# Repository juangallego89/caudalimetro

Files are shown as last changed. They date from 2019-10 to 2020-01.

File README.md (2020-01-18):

# Proyecto IoT para monitorear el consumo de agua en múltiples viviendas

Nombre del proyecto: Diseño e implementación de un sistema IoT para gestionar el consumo de agua en el hogar

Universidad Cooperativa de Colombia 
Facultad de Ingenierías 
Programa de Ingeniería de Sistemas 
Villavicencio, Meta
2020

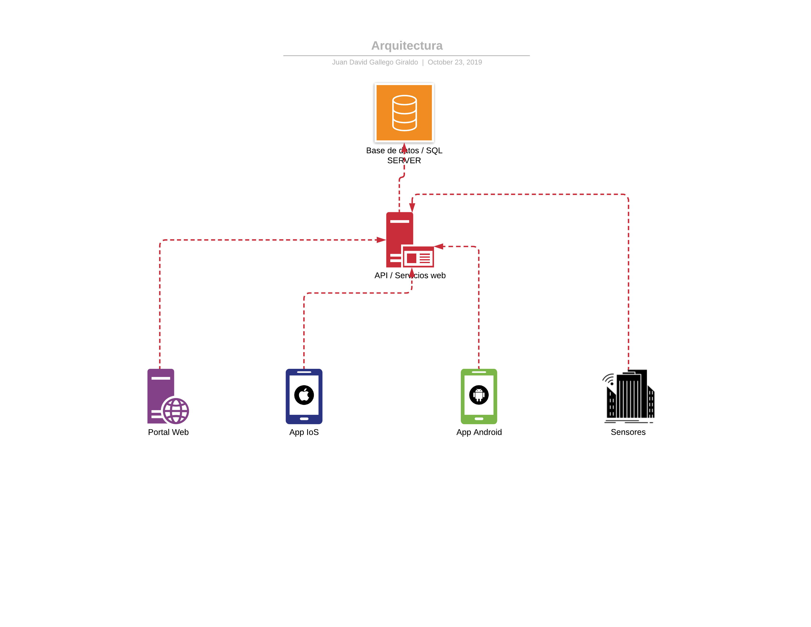
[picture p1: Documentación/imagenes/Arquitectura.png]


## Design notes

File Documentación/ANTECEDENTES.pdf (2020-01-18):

Diseño de un prototipo para la medición del consumo de agua en un grifo de

una unidad habitacional a través de la tecnología ZigBee

Gisell Granados Quitian & Javier Pérez Ombita Junio 2017

Asesor metodológico y técnico

Daniel Bejarano Segura
Lic. Matemáticas y Física

Universidad Cooperativa de Colombia

Facultad de Ingenierías

Programa de Ingeniería de Sistemas

Villavicencio, Meta

Junio, 2017

Contenido

Lista de Figuras

Lista de Tablas

Resumen

Este proyecto de investigación tiene como objetivo de desarrollar un sistema automatizado

que mida y monitoree el consumo de agua, el cual se instala en la tubería que conecta con

diversos grifos de una unidad habitacional, de tal forma que al abrir la llave se sepa con exactitud

el valor de litros de agua que se gastaron en el tiempo de apertura de la llave. El hardware del

prototipo está integrado por un sensor de flujo que mide el gasto en tiempo real y envía los datos

de forma inalámbrica, a través del protocolo de comunicación Zigbee, a una placa de Arduino

mega, esta placa procesa la información y la envía a una base de datos para que el usuario, por

medio de una aplicación móvil, pueda monitorear al consumo. Se usaron varios lenguajes de

programación como JAVA, para el desarrollo de la app y SQL, para el desarrollo de la base de

datos. Se realizó una investigación aplicada con enfoque tecnológico, ya que se transformaron

los conocimientos adquiridos en el desarrollo tecnológico del prototipo. Se pretende automatizar

un proceso que en la actualidad no es posible realizar con facilidad, y es el de monitorear el

consumo del agua por grifo.

Palabras clave: aplicación móvil, consumo de agua, ZigBee.

Abstract

The research project aims to develop an automated system that measures and monitors the

consumption of water, which would be installed in the pipeline that connects with various

faucets within the home, and would measure the exact number of litres of water that were

consumed over a period of time. The prototype hardware would consist of a flow sensor that

measures the real-time water use and sends the data wirelessly through the Zigbee

communication protocol to a Mega Arduino Board. This board processes the information and

sends it to a database. A mobile application can also be used to monitor consumption. Several

programming languages like JAVA were used for the development of the application and SQL

for the development of the database. Applied research is carried out with a technological focus,

since the acquired knowledge in the technological development of the prototype was

transformed. It is intended to automate a process that at present is not possible to perform easily,

and to monitor the consumption of tap water.

Key words: Movil App, water demand, ZigBee.

Introducción

Los cambios climáticos, el consumo inadecuado en los hogares, el aumento y desarrollo de la

población, son algunos de los factores que causan un mayor gasto del agua en la actualidad. Para

el DANE las viviendas tienen una ocupación de entre 4 o menos personas (DANE, 2010, p.2),

las cuales usan el agua ya sea para bañarse, lavarse las manos o cocinar sus alimentos, entre

otros. Ojeda (2009) plantea que el “consumo básico de agua potable en Colombia es de 20

m3/vivienda-mes, equivalente a 133 litros/habitante -día y que este consumo en su mayoría es

30% mayor al estándar” (p.11) es decir que se está consumiendo por hogar más de lo que

corresponde.

En las residencias son usados los contadores o medidores de agua, que son los que se

encargan de registrar el consumo para su posterior cobro, pero en la mayoría de las ocasiones no

registran el total del agua que se consume.

En la actualidad, con el desarrollo y evolución de las tecnologías, se han adoptado mejores

métodos que ayudan a administrar este recurso hídrico que llega a los hogares. Según Bustillos,

Hernández, Silva, Barrón, Chávez, & López (2016), una tecnología actual que ayuda con la

automatización y medición del consumo de agua de las redes domésticas, sin ser creada para

esto, es ZigBee (p. 1), ya que con la integración de otros métodos (sensores, placas electrónicas,

nodos inalámbricos) logra transferir de forma inalámbrica y en tiempo real el consumo de cada

salida de agua, si se requiere.

Con el desarrollo de esta investigación y utilizando tecnologías como ZigBee, Arduino,

sensores entre otras, se pretende ayudar al hombre a obtener la medición exacta del agua que

consume en su hogar y así, contribuir con el ahorro de este líquido vital.

Capítulo 1. Descripción del Proyecto

1.1.Planteamiento del problema

1.1.1. Descripción.

La falta de conciencia en el uso racional y el consumo inadecuado del agua hacen evidente la

necesidad de medir el gasto en tiempo real del consumo que se hace en una unidad habitacional.

Actualmente, para medir el consumo son utilizados los medidores de agua, contadores o

hidrómetros, los cuales permiten contabilizar la cantidad de agua que pasa a través de ellos.

Según Ojeda (2009), “el mal uso que se le da al agua en los hogares es que el 52% del agua

suministrada no se contabiliza, el 48% del agua suministrada se factura y el 28% del valor del

agua suministrada se recauda” (p.11), es decir que, en muchas ocasiones estos medidores de agua

no registran la totalidad del líquido que entra a una vivienda y esto conlleva a tener un deficiente

control del uso.

Cada vez que una persona quiere saber el consumo de agua en tiempo real de una vivienda

debe ir hasta el contador y observar el registro que este está indicando, de otra forma, se deben

esperar los reportes que llegan a los hogares de manera mensual, y para esto, esperar a que un

funcionario de la empresa del acueducto realice la lectura del contador.

El problema es mayor cuando se desea conocer permanentemente el consumo de cada grifo;

al tener un único contador esto resulta imposible porque este capta al mismo tiempo el consumo

de los grifos que estén en uso, ya sea uno o más.

Pasa de igual forma si la persona quiere saber el valor de su consumo general o por grifo,

como no tiene acceso en tiempo real a los datos que registra el contador, debe esperar a que

llegue su factura, teniendo en cuanta que va a ser general y no por grifo.

Estas problemáticas se podrían solucionar si se creara un dispositivo tecnológico que ayude a

monitorear el consumo de cada salida de agua o grifo y así se tendría registro en tiempo real del

consumo, además de calcular el valor del gasto parcial y total que se genera en una unidad

habitacional.

1.1.2. Formulación del Problema.

La presente investigación consiste en el diseño de un prototipo, apoyados en la tecnología

Zigbee, que facilite el monitoreo en tiempo real de un punto de consumo de agua; para lo

anterior, se puede formular la siguiente pregunta de investigación:

¿Es posible monitorear en tiempo real el consumo de agua en un grifo de una unidad

habitacional?

1.2.Objetivos

1.2.1. Objetivo general.

Desarrollar un prototipo que ayude a la medición y monitoreo del consumo de agua en un

grifo de una unidad habitacional.

1.2.2. Objetivos específicos.
- Construir un prototipo para la medición del consumo de agua de un grifo de una unidad

habitacional.

- Desarrollar una base de datos para almacenar la información del consumo de agua que

genera el grifo.

- Implementar la tecnología Zigbee como medio de transmisión inalámbrico de los datos

del prototipo a la base de datos.

- Desarrollar una aplicación móvil que monitoree el consumo de agua en un grifo de una

unidad habitacional.

1.3.Justificación

Este proyecto de investigación pretende contribuir al uso eficiente y consciente del agua,

creando un prototipo que monitoree el consumo en tiempo real. Lo anterior se da ya que se

encontró que el actual sistema para medir el consumo no registra exactamente el gasto del fluido

que ingresa a las tuberías, además de que no muestra en tiempo real el gasto que se hace por

salida de agua o grifo de una unidad habitacional.

El proyecto tiene el objetivo diseñar un prototipo que ayude al registro y control del agua, ya

que en la actualidad se está viendo que no se le da un buen y adecuado uso en las viviendas por

parte de las personas que las habitan.

El prototipo posibilita el monitoreo en tiempo real del gasto del agua por cada salida que

exista en la unidad habitacional, registrándolo en una aplicación móvil (APP) para que el usuario

sepa sobre su consumo y así mismo si está accediéndolo tome consistencia y realice control del

consumo.

Se emplea la tecnología Zigbee ya que es el protocolo que más se adapta a la investigación,

permitiendo la comunicación inalámbrica entre los diferentes nodos del prototipo y la transmisión de información a la base de datos, además los módulos que se utilizan consumen

energía solo cuando se están usando, de manera contraria están en un estado de poco consumo.

El proyecto se desarrollará en la modalidad de grado de auxiliar de investigación, del proyecto

“Diseño e implementación de un sistema de monitoreo y concientización del consumo de agua

en grifo comercial utilizado en unidades habitacionales basado en el protocolo de internet de las

cosas”, liderado por el Magister en educación Daniel Bejarano y el Magister en seguridad

informática Carlos Ignacio Torres, de la facultad de ingenierías de la Universidad Cooperativa

de Colombia, sede Villavicencio, dentro de la línea de investigación de desarrollo de software.

El área de aplicación se consideró porque teniendo una unidad habitacional un contador no es

posible monitorear en tiempo real el consumo de cada grifo, esto se mejorará con desarrollos

tecnológicos que ayuden a la administración del líquido en los hogares.

1.4.Marco Referencial

Para desarrollar el prototipo es importante tener claro los conceptos teóricos que soportan

la investigación.

1.4.1. Marco Teórico.

1.4.1.1.Zigbee.

ZigBee es un protocolo de comunicación inalámbrico que se basa en el estándar IEEE

802.15.4 de las redes inalámbricas WPAN (Acevedo & Turriago, 2013, p.1).

Esta tecnología es impulsada por ZigBee Alliance y permite interconectar más de 2 nodos

logrando transferencia de datos. Maneja velocidades de transmisión entre 20 y 250 Kbps,

funcionando en la banda sin licencia de 2,4 GHz Osorio, (Garzón & Giraldo, 2008, p.3), para enlaces con alcance de 40 m en interiores (edificio de oficinas, domicilios) y 120 m en exteriores

(con línea de vista).

Este protocolo es utilizado actualmente para desarrollos en domótica, gracias a su poco

consumo de energía, la topología de red en malla y su fácil integración con elementos

electrónicos; su aplicación facilita procesos de monitoreo, control de iluminación, calefacción,

riego.

Esta tecnología soporta tres tipos de topología:

- Estrella: presenta larga vida útil como consecuencia del bajo consumo que requiere.
- Malla: en la cual existen múltiples rutas para alcanzar un destino, obteniéndose alta

confiabilidad.

- Racimo de Árbol: es una topología del tipo Malla-Estrella que encierra los beneficios

de ambas.

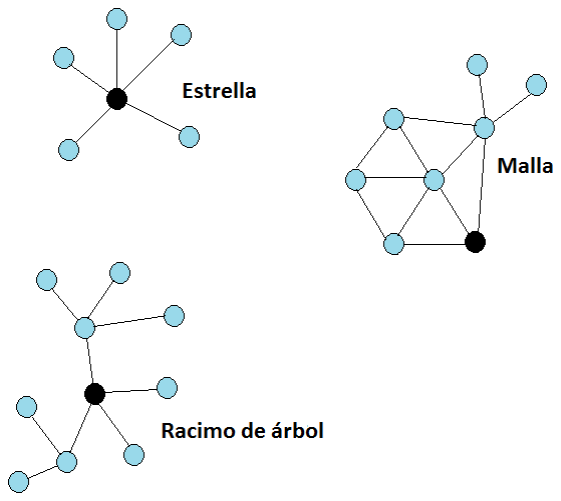
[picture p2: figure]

Figura 1. Topologías. Fuente: Elaboración propia.

1.4.1.2.Módulo XBee.

Los módulos XBee son fabricados por DIGI y están basados en el protocolo de ZigBee, estos

chips son capaces de comunicarse de forma inalámbrica con otros. Según Algarín (2012) “se

puede constituir una red de datos confiable, con alta inmunidad al ruido, facilitando la

comunicación entre los componentes del sistema y asegurando el correcto transporte de la

información desde y hacia las unidades remotas” (p.3).

1.4.1.3.Medidores de flujo de agua domiciliaria.

Cuando se habla de medidores de flujo de agua o caudal, se hace referencia a un instrumento

ubicado en la tubería, que es capaz de contabilizar la cantidad (en volúmenes) de agua que pasa

por ella; según Ordoñez (2007) “los medidores que existen en el mercado miden flujos desde

mililitros por segundo (ml/s) para experimentos precisos de laboratorio, hasta miles de metros

cúbicos por segundo (m³
/s) para sistemas de irrigación de agua o agua municipal” (p.4).

A continuación, se observan los tipos de medidores que existen:

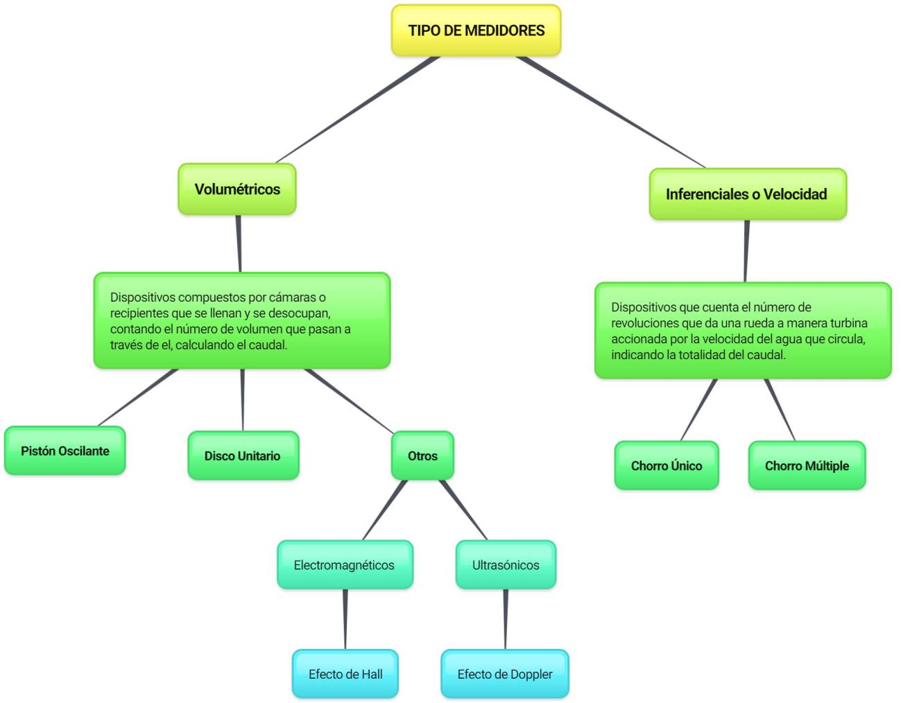
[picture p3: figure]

Figura 2. Tipos de medidores de caudal. Fuente: Elaboración propia.

1.4.1.4.Arduino.

En la página web de Arduino se encuentra que, Arduino es una plataforma electrónica de

código abierto basado en hardware y software, fácil de programar y de usar. Las placas de

Arduino son capaces de leer señales de sensores y convertirlas en salidas (la activación de un

motor, encender un LED, publicar algo en línea). Para ello utiliza el lenguaje de programación de

Arduino, y el software de Arduino (IDE), basadas en el procesamiento.

Este microcontrolador se utiliza en miles de proyectos de diferentes áreas por su característica

de código abierto y su compatibilidad con un sin número de sensores, dispositivos de

comunicación, leds, servo motor, entre otros.

1.4.1.5.Base de datos.

“Una base de datos es un conjunto de elementos de datos interrelacionados, administrados

como unidad” (Oppel, 2010, p. 16). Las bases de datos han ido avanzando al mismo tiempo que

las tecnologías, los registros muestran que fueron las cintas magnéticas las primeras bases de

datos utilizadas, en las cuales se almacenaba la información y solo podía ser leída de forma

secuencial y ordenada.

Existen herramientas que facilitan el uso, la actualización y la consulta de una base de datos,

estas herramientas son los Sistemas Gestores de Bases de Datos (SGBD), que cumplen las

funciones de:

- Permitir a los usuarios almacenar, acceder, actualizar datos.
- Permitir el acceso a los datos por varios usuarios al mismo tiempo, es decir la

concurrencia.

- Salvaguardar la información que exista en la base de datos, de manera que no se

pierda.

- Asegurar la información, de modo que solo los usuarios que tengan permiso de

acceder a la base de datos puedan ver la información.

Algunos SGBD más utilizados son: Oracle, MySQL, PostgreSQL, Microsoft SQL Server.

1.4.1.6.Aplicaciones móviles.

La palabra aplicaciones viene del inglés “apps” que se deriva de “application” y que en

español traduce “aplicación”. Se conoce como aplicación móvil al software que se instala en un

dispositivo móvil con el fin de ampliar sus funcionalidades, para que el usuario realice diferentes

tareas (Arroyo 2011, p. 36)

Según Aguado& Martínez (2013), “el entorno actual de los contenidos y aplicaciones móviles

no es consecuencia directa del desarrollo lineal y planificado de un modelo inicial, si no que ha

surgido como resultado de la evolución vivida el negocio de las telecomunicaciones y su

confluencia con otros mercados” (p. 14).

Es probable que ya existan aplicaciones para todo: jugar, estudiar, enviar mensajes, escuchar

música, ver películas, publicar información, controlar aparatos, navegar por internet etc., pero

cada día surgen necesidades en la sociedad que deben ser solucionadas de distintas maneras y

con nuevas aplicaciones.

Se pueden desarrollar aplicaciones en diferentes lenguajes de programación como Java, C#,

Visual Basic, Objective-C, Swift, entre otros, teniendo en cuenta el sistema operativo para el cual

se diseñe la aplicación.

Entre los sistemas operativos más utilizados por dispositivos móviles están:

Android.

Es un sistema operativo multidispositivo, inicialmente diseñado para teléfonos móviles. En la

actualidad se puede encontrar en ordenadores, tabletas, GPS, televisores, etc. Este sistema

operativo permite programar aplicaciones empleando Java (Robledo& Fernández 2011, p.12).

Fue desarrollado por la compañía Android Inc, que en el año 2005 fue comprada por Google.

Actualmente Android es ejecutado como sistema operativo en múltiples teléfonos de mascas como: Samsung, LG, Lenovo, Motorola, Sony, Wuawei, entre otros, siendo el sistema operativo

que en la actualidad tiene mayor presencia en los móviles.

IOS.

Nace a mediados de año 2007, llamándose IPhone OS. Es desarrollado originalmente para el

IPhone, pero más tarde fue introducido a el IPod Touch y el IPad, desde si primera versión

incorpora aplicaciones como Mail, Fotos, Calculadora, entre otras. Utiliza como lenguaje de

programación para crear sus aplicaciones Objective-C y Swift.

BlackBerry OS.

Es desarrollado por RIM, este sistema operativo es propietario de BlackBerry. La versión del

sistema operativo tiene un Kernel que se basa en Java, además, es un sistema operativo

multitarea, pues permite ejecutar más de una aplicación al tiempo. Sus aplicaciones móviles son

desarrolladas en Java, en diferentes entornos de desarrollo.

Windows Phone.

Este sistema operativo fue lanzado en el año 2010. Entre las novedades se encuentra la

denominada interfaz de usuario “Metro” basada en la utilización de mosaicos dinámicos que

muestran información útil al usuario. Actualmente corre en teléfonos de Microsoft, la linea de

teléfonos que le compro a Nokia en el año 2013 y se utilizan como lenguajes de programación

C# y Visual Basic.

1.5.Metodología

Para esta investigación se han aplicado dos metodologías, las cuales son la metodología de

investigación y la metodología de ingeniería

1.5.1. Metodología de Investigación.

La presente investigación es de tipo aplicada con enfoque tecnológico, ya que se pretende

transformar el conocimiento adquirido en el desarrollo tecnológico de un prototipo que va a

satisfacer una necesidad social previamente identificada.

El método tecnológico cuenta con las siguientes fases (Ortiz 2005, p.43).

- Selección del problema
- Desarrollo de hipótesis
- Prueba de hipótesis
- Comprobación de resultados
- Comunicación
1.5.2. Metodología Ingenieril.

Se hizo un análisis de las diferentes metodologías de desarrollo que existen y se concluyó que

la mejor opción a aplicar es la metodología de prototipos, porque se acopla a las necesidades del

proyecto permitiendo escuchar los requerirnos iniciales del tutor para hacer un primer modelo

funcional, con el cual se podrá interactuar y si es el caso hacer cambio en las siguientes

iteraciones.

Esta metodología reduce el riesgo de construir un producto que no satisfaga las necesidades

del tutor.

Para ejecutar esta metodología se tienen en cuenta sus etapas que son las siguientes

(Pressman, 2005, p. 39).

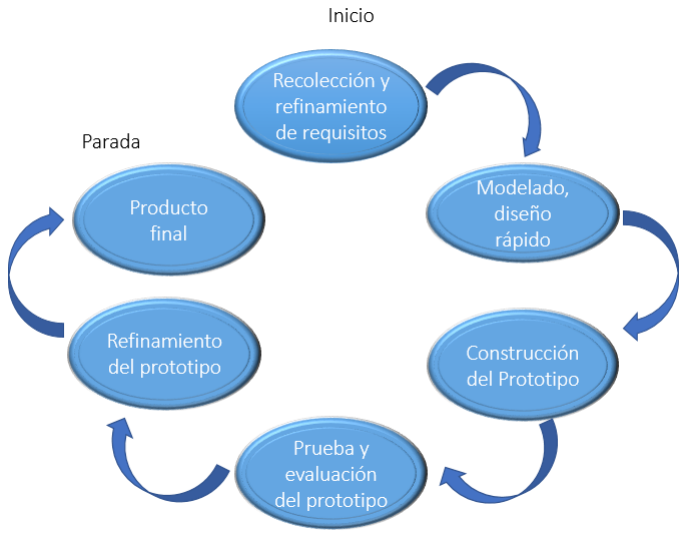
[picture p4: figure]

Figura 3. Fases de la metodología prototipos. Fuente: Elaboración propia.

Capítulo 2. Descripción De Las Actividades Realizadas

Con el desarrollo de la investigación se realizaron diferentes actividades para poder construir

el prototipo funcional, de igual manera se establecieron reuniones entre los tutores y los

auxiliares de investigación y para tener claros los objetivos finales del proyecto.

Se estableció un cronograma (ver figura 4) para facilitar el desarrollo de las actividades y

tener clara la fecha de inicio y fin de cada actividad que comprende el proyecto.

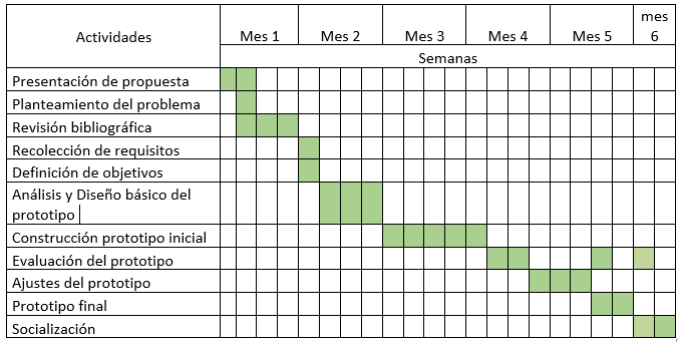
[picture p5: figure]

Figura 4. Cronograma de actividades. Fuente: Elaboración propia.

2.1.Presentación De La Propuesta Y Planteamiento Del Problema

Se presentó el proyecto de investigación “Diseño e implementación de un sistema de

monitoreo y concientización del consumo de agua en grifo comercial utilizado en unidades

habitacionales basado en el protocolo de internet de las cosas” por parte del Magister en

educación Daniel Bejarano, quien es el investigador principal y el Magister en seguridad informática Carlos Torres a dos de los estudiantes del programa de Ingeniería de Sistemas, los

cuales tomarían el papel de auxiliares de investigación.

De igual manera, se planteó la problemática a solucionar y se trazaron unos objetivos a

cumplir.

2.2.Revisión Bibliográfica

Después de tener claro la problemática a solucionar, se realiza una investigación documental

en diferentes fuentes de información como bases de datos, bibliotecas, bibliotecas virtuales, en

las cuales se logra recopilar diferentes trabajos, libros, tesis, revistas, artículos con información

sobre tecnologías inalámbricas, consumo de agua, aplicaciones móviles, bases de datos,

metodologías; información que es de vital importancia para adquirir nuevo conocimiento.

Se diseñan algunas fichas bibliográficas (ver los anexos), en las cuales se destaca la

información más relevante e importante para aplicar en el desarrollo del proyecto.

2.3.Recolección De Requisitos

Se establecieron con los tutores del proyecto los requerimientos, los cuales estuvieron sujetos

a actualizaciones durante la fase de evaluación del prototipo. A continuación, se mencionan los

requerimientos tanto funcionales como no funcionales del proyecto.

2.3.1. Requerimientos no Funcionales.

Tabla 1. Requerimientos no funcionales.

ID | Nombre | Descripción
R-01 | Usabilidad | El prototipo debe ser fácil de usar por el usuario

R-02 | Disponibilidad | El prototipo debe ser funcional para que el usuario lo utilice cada vez que lo requiera
R-03 | Aplicación móvil para Android | La aplicación será compatible con los teléfonos que tengan como sistemas operativo Android
R-04 | Interfaz amigable | La interfaz de la aplicación debe poder utilizarse por el usuario de forma fácil y sencilla.

Fuente: Elaboración propia.

2.3.2. Requerimientos Funcionales de la APP.

Tabla 2. Requerimientos funcionales.

ID | Nombre | Descripción
R-01 | Visualizar consumo | El sistema proporciona la información al usuario del consumo de agua
R-02 | Visualizar costo de consumo | El sistema proporciona la información al usuario del costo en pesos del consumo de agua
R-03 | Actualizar | Se actualizan los datos de consumo y costo de consumo de agua.

Fuente: Elaboración propia.

2.4.Definición de Objetivos

De acuerdo con las necesidades y requerimos que se establecieron, surgieron los objetivos que

como auxiliares de la investigación se debieron cumplir. Estos objetivos, el general y los

específicos, se pueden observar en el primer capítulo del documento.

2.5.Análisis Y Diseño Básico Del Prototipo

Gracias a los requerimientos funcionales recopilados, se diseña el diagrama de casos de uso

como base para empezar la construcción del prototipo.

2.5.1. Casos de uso para la APP.

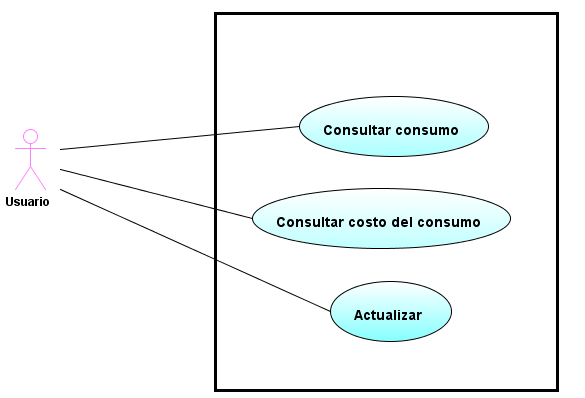
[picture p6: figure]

Figura 5. Casos de uso. Fuente: Elaboración propia.

2.6.Construcción del Prototipo

La construcción del prototipo se divido en 4 fases por ser un proyecto que integra diferentes

componentes electrónicos y tecnológicos.

Tabla 3. Componentes electrónicos utilizados para la construcción del prototipo.

Concepto | Descripción | Cant.
Módulo XBee | Módulo de comunicación por radio | 2
Arduino Mega | Tarjeta de desarrollo basada en un microcontrolador | 2

G1/2 Sensor de flujo de agua | Sensor de flujo de agua | 1
Unidad XBee Explorer USB | Tarjeta para programar los módulos XBee | 1
Unidad regulada para módulos XBee | Tarjeta reguladora de voltaje. | 2
Base SMD de 10 pines y 2mm para XBee | Base SMD de 10 pines y 2mm para XBee | 4
Header hembra para Arduino | Conector header hembra de 6 pines para Arduino. | 2
Conector header macho | Conector header macho de 40 pines, en una línea. | 1

Fuente: Elaboración propia.

Tabla 4. Componentes tecnológicos utilizados para la construcción del prototipo.

Concepto | Descripción
XCTU | Aplicación para configurar, inicializar, actualizar firmware y testear los módulos XBee.
MySQL | SGBD utilizado para almacenar la información que genera el sensor de caudal.
XAMMP | Programa que permite la gestión de bases de datos MySQL y servidor web Apache.
JSON | (JavaScript Object Notation - Notación de Objetos de JavaScript) es un formato ligero de intercambio de datos.
PHP | Lenguaje de código libre.
Android Studio | IDE para desarrollar la aplicación móvil.

Fuente: Elaboración propia.

2.6.1. Construcción Simulación Del Grifo.

Para fabricar una simulación de un grifo se utilizaron los siguientes materiales:

- 01 botellón de agua con capacidad de 20 litros.
- Silicona trasparente.
- 1 llave de grifo PVC.
- Pegante para PVC.
- 30 cm de tubo PVC de (1/2) pulgada.
- 01 reducción de 1(1/4) a (1/2) pulgadas.
- 01 codo PVC de (1/2) pulgada.
- 02 adaptadores hebra PVC de (1/2) pulgada.
- 01 base metálica ornamentada para sostener el botellón.

Una vez ensamblados estos elementos, se obtuvo un grifo con la suficiente capacidad de agua

para realizar las respectivas pruebas del prototipo.

Se instaló el sensor de caudal antes de la salida final de agua como lo muestra la figura 5, para

calcular en este punto el volumen de líquido que saldrá.

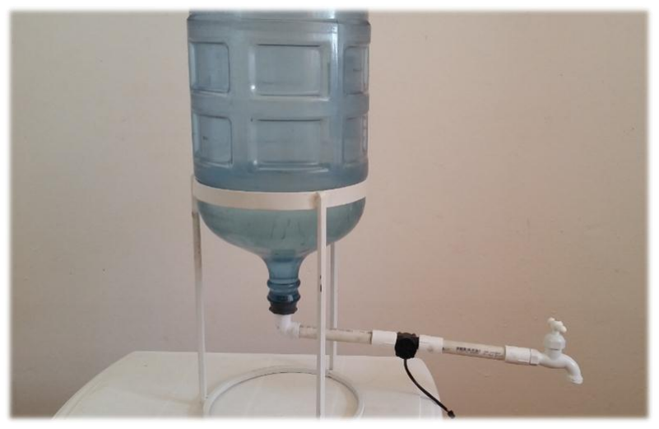
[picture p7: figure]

Figura 6. Foto de la simulación del grifo. Fuente: Elaboración propia.

2.6.2. Construcción De Base De Datos.

El prototipo requiere del desarrollo de una base de datos para almacenar la información del

consumo de agua, información que emite el sensor de caudal que se instaló en la tubería que

lleva al grifo. La base de datos se desarrolló en el sistema de gestión de base de datos o SGBD

MySQL y se diseñó un modelo entidad relación pensado en la implementación de un sistema

completo que cuente con varios nodos terminales que envían información a uno central, pero que

permita por el momento realizar pruebas con un solo nodo

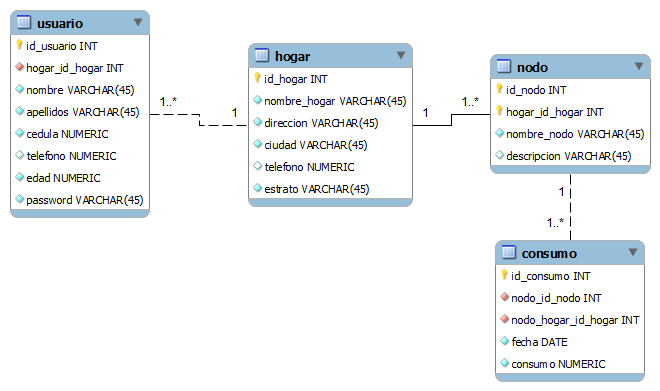
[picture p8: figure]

Figura 7. Modelo entidad relación (MER) del prototipo. Fuente: Elaboración propia.

El eje central de la base de datos es el hogar (ver Figura 7.) en el cual se instalará el sistema.

Esta unidad habitacional tendrá unos usuarios que tendrán acceso a la información que vayan

capturando los diferentes nodos.

2.6.3. Construcción De Nodos.

Como medio de transmisión de datos se utilizaron 02 módulos Xbee SC2. Uno es el nodo

emisor, el cual se encargará de enviar las pulsaciones emitidas por el sensor de caudal que está

en la tubería, cada vez que salga agua por el grifo.

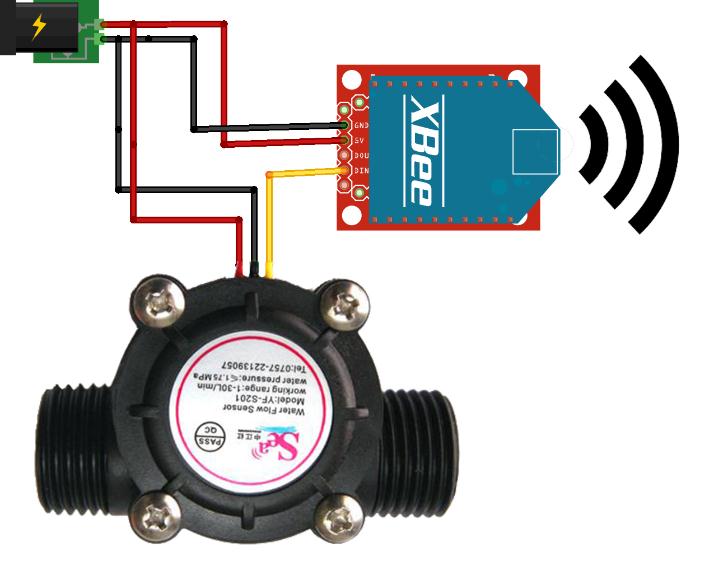
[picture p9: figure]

Figura 8. Conexión del sensor con el módulo XBee emisor. Fuente: Elaboración propia.

El segundo nodo recibirá la información transmitida y la enviará al pin 2 de la placa Arduino

que se encargará de procesar la información.

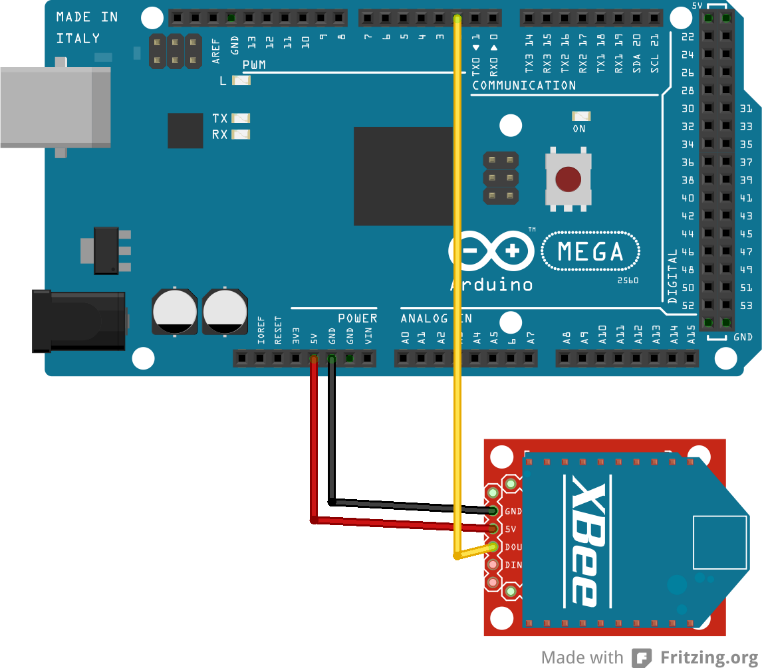
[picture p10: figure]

Figura 9. Conexión de la placa Arduino con el módulo receptor XBee. Fuente: Elaboración propia.

Las placas de Arduino, en este caso la versión Mega 2560, cuentan con pines para diferentes

propósitos como entradas o salidas digitales, análogas, PWM, entre otros. Pero específicamente

los pines 2 y 3 están programados para realizar conteos de pulsaciones digitales, con el fin de

hallar su frecuencia mediante la función attachInterrupt(). Obteniendo la frecuencia, se logra

hacer una conversión a caudal (Q), por medio de la utilización de una constante de conversión

(K) que es suministrada por el fabricante de sensor de caudal.

### f(Hz) = K ∗ Q(l min) → Q (l⁄min) =

### f(Hz)

K

⁄

Figura 10. Fórmula para determinar la frecuencia. Fuente: Elaboración propia.

Para el sensor de caudal YF-S201 de 1⁄2 ", la constante de conversión es K=7,5.

El promedio de salida de agua por el grifo se calculó en 1.75 litros. Sin embargo, el promedio

que arrojaba el sensor era de 1.42 litros. Por este motivo se tuvo que ajustar la constante K, con

ayuda de la formula ya expuesta.

Q (l⁄min) =

f(Hz)
K

1,75 (l⁄min) =

10,5(Hz)
K

K = 6

Figura 11. Constante de conversión K. Fuente: Elaboración propia

De esta manera se comprobó que cada sensor necesita de una calibración, para lograr una

medición más exacta.

Las mediciones se envían a la base de datos mediante un web service programado en PHP,

teniendo en cuenta que para la base de datos se utilizó MySQL.

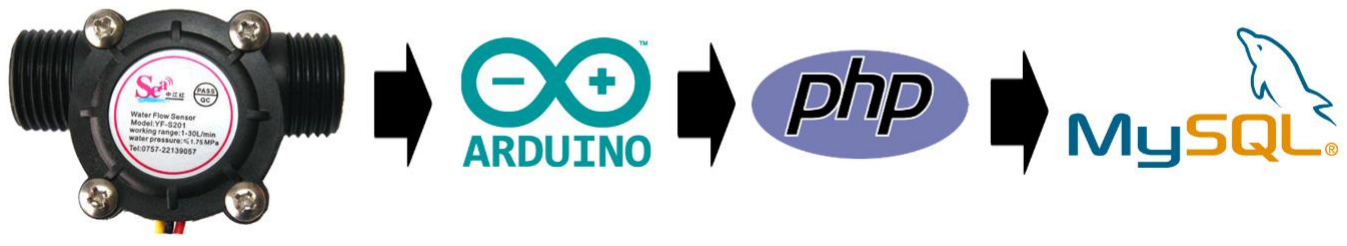
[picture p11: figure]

Figura 12. Herramientas utilizadas para almacenar los datos de consumo. Fuente: Elaboración propia.

2.6.4. Construcción Aplicación Móvil.

Teniendo en cuenta que para realizar las pruebas al prototipo se utilizará un servidor local, se

utilizó el IDE Android Studio para desarrollar la aplicación móvil, ya que este entorno facilita la

organización de los proyectos, separando la parte lógica de las vistas y sus recursos. Además,

permite el uso de bases de datos en MySQL mediante la utilización de web services y la

interacción con JSON (JavaScript Object Notation) para transmitir información desde PHP a la

aplicación.

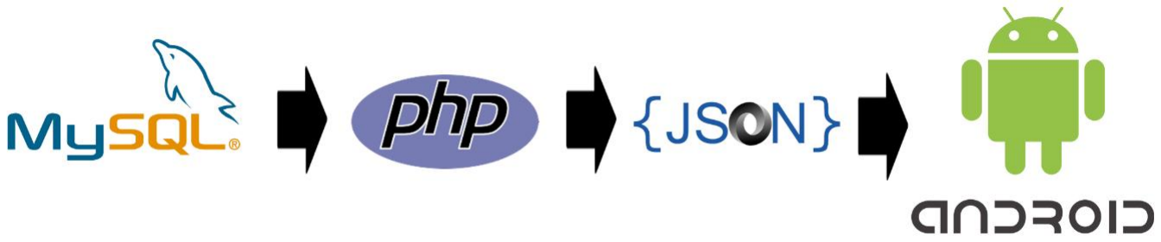
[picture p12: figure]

Figura 13. Herramientas utilizadas para visualizar los datos del consumo. Fuente: Elaboración propia.

La interfaz de la aplicación nos ofrece dos campos tipo TextView en los cuales se refleja la

suma total del consumo de agua hasta la fecha, en metros cúbicos y el valor de este consumo en

pesos colombianos, en base a la tarifa actual que ofrece la empresa de acueducto y alcantarillado

en la ciudad de Villavicencio. Finalmente, la aplicación cuenta con un botón que actualiza la

información de la base de datos, si se han realizado nuevos registros por parte del sensor de

caudal.

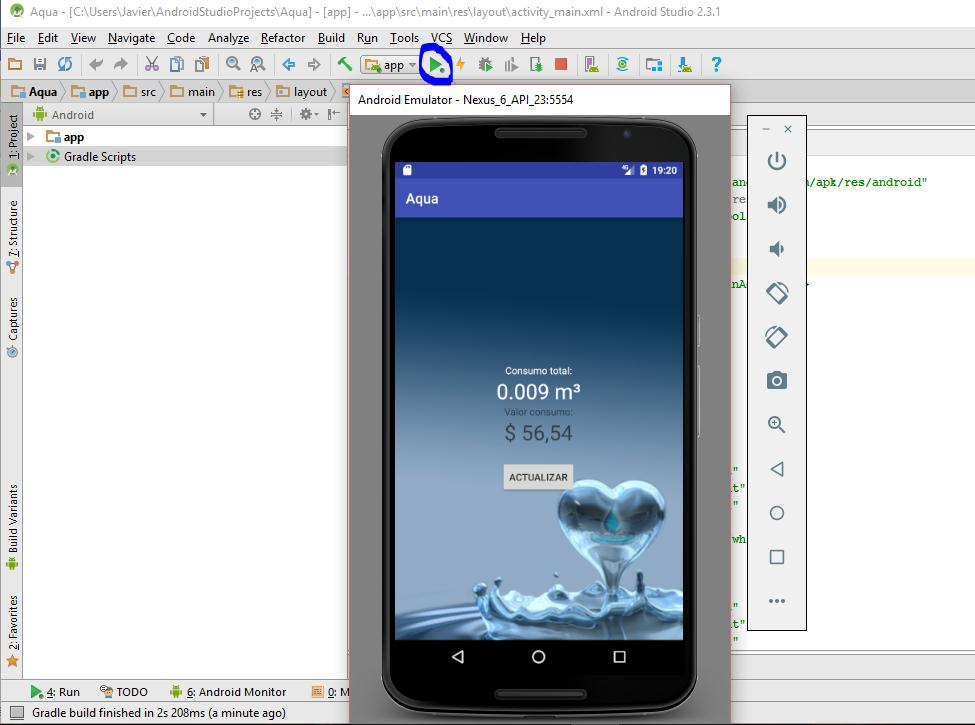
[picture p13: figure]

Figura 14. Visualización de la aplicación móvil. Fuente: Elaboración propia.

2.7.Evaluación Del Prototipo

Para evaluar el prototipo se tuvieron en cuenta criterios como la funcionalidad, la facilidad de

uso, la compatibilidad, la estabilidad, la interoperabilidad, la actualización y el costo final y

futuro del prototipo. Además de esto, se tuvo en cuenta por parte de los tutores que se cumpliera

los objetivos trazado. En los nexos se pueden observar la evaluación que se realizó .

### 2.8. Ajuste del Prototipo

Durante la construcción de prototipo en la fase de la construcción de los nodos se hizo un

análisis para hallar la constante K, ya que para el sensor de caudal YF-S201 de 1⁄2 ", la constante

de conversión es K=7.5 según su fabricante. Al hacer las pruebas se observó que el promedio de

salida de agua que arrojaba el sensor era de 1.42 litros, este valor no coincidía con el promedio

que se había calculado el cual era de 1.75 litros. Por este motivo se tuvo que ajustar la constante

K de la siguiente forma:

Q (l⁄min) =

f(Hz)
K

1,75 (l⁄min) =

10,5(Hz)
K

K = 6

Figura 15. Constante de conversión K. Fuente: Elaboración propia

De esta manera se comprobó que cada sensor necesita de una calibración, para lograr una

medición más exacta.

### 2.9. Prototipo Final

2.9.1. Descripción del Prototipo.

Gracias a la integración de diferentes componentes electrónicos y tecnológicos se logra

diseñar y construir un prototipo completamente funcional, el cual mide en tiempo real el

consumo de agua de un grifo y calcula el valor de este consumo.

Este prototipo pretende comprobar la posibilidad de medición de agua en un grifo de una

unidad habitacional, mediante la utilización del protocolo de transmisión de datos Zigbee.

Para dicho propósito se usará una simulación de un grifo de agua, que realizará las

mediciones del flujo de líquido mediante la utilización de un sensor de caudal de efecto Hall.

Esta información se almacenará en una base de datos, para poder verificarla mediante una

aplicación móvil, desarrollada en el sistema operativo Android.

El prototipo completo permitirá realizar las siguientes acciones:

1) Efectuar las mediciones de flujo de agua en la simulación de un grifo.
2) Enviar la información a un nodo central, para procesarla y almacenar en una base de

datos los resultados.

3) Acceder a la información de la base de datos mediante una aplicación móvil.
4) Brindar la opción de actualizar la información reflejada en la aplicación móvil, si se

realizan nuevas mediciones.

2.9.2. Componentes.

El prototipo final se compone de una simulación de un grifo de agua (ver Figura 16), en el que

se encuentra instalado un sensor de caudal, el cual se encarga de determinar cuándo está

circulando el agua por la tubería.

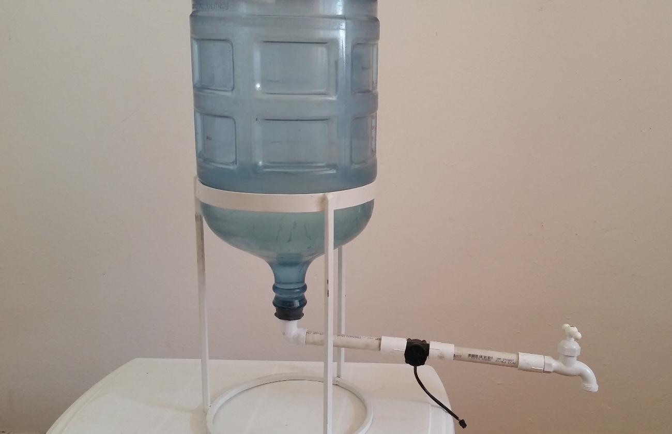
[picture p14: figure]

Figura 16. Simulación del grifo de agua con el sensor. Fuente: Elaboración propia.

Existe un nodo terminal que está compuesto por un módulo XBee, el cual está conectado con

el sensor de caudal para transmitir la información (pulsaciones) que arroja el sensor cada vez que

se abre el grifo y pasa el agua.

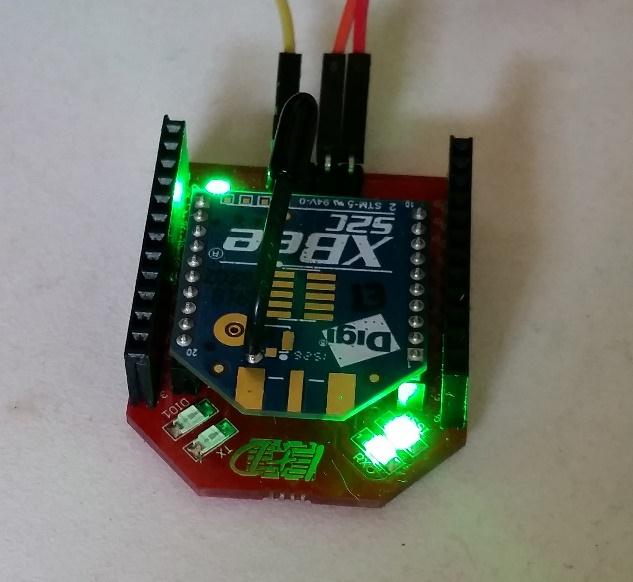
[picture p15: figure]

Figura 17. Nodo Terminal. Fuente: Elaboración propia.

De igual forma existe un nodo coordinador (ver Figura 18) que se encarga de recibir la

información que es emitida por el nodo terminal. Este nodo está compuesto por una placa

Arduino y un módulo XBee.

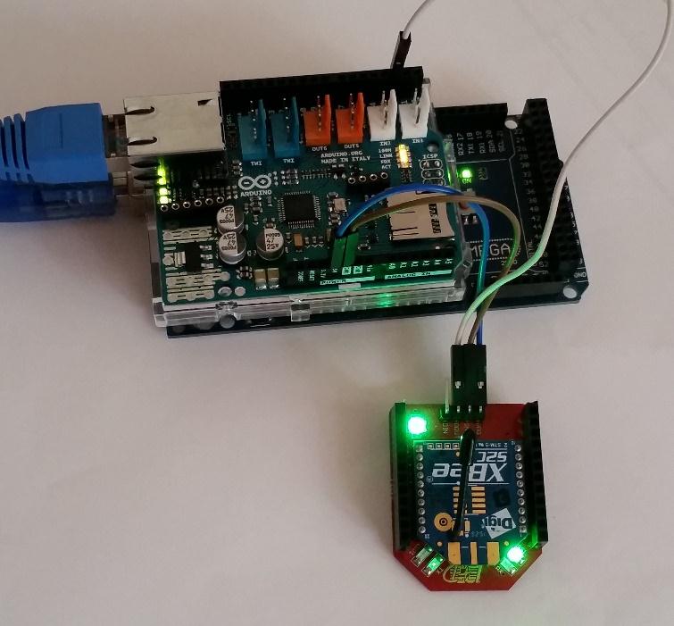
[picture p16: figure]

Figura 18. Nodo coordinador. Fuente: Elaboración propia.

Luego de que la información llega al nodo coordinador, es enviada a la base de datos, para ser

almacenada y posteriormente se pueda reflejar en la aplicación móvil.

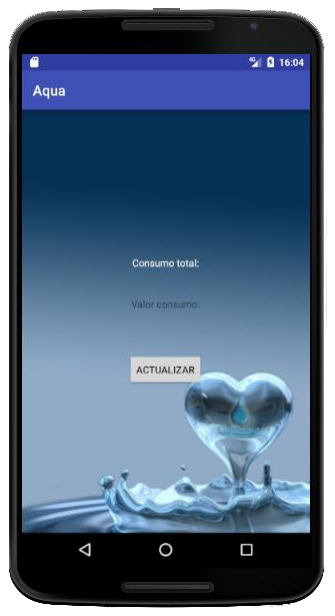
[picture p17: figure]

Figura 19. Aplicación móvil. Fuente: Elaboración propia.

En la aplicación móvil se refleja el consumo total que se ha registrado por el sensor hasta la

fecha, en metros cúbicos. Ya que esta medida es la utilizada en los recibos de acueducto en

Colombia. Además, se hará el cálculo del consumo en base a la tarifa establecida en la Empresa

de Servicios Públicos de Villavicencio, según el estrato (para el caso del grifo simulado, estrato

3).

### 2.10. Socialización

Se muestra el prototipo durante una exposición que se realiza a los tutores, el investigador

principal y los demás investigadores del proyecto. Junto con la socialización de se entrega el

manual de usuario y el prototipo final y funcional.

Capítulo 3. Aporte De Experiencia Para Formación Profesional

Con el desarrollo de esta investigación que tiene como eje central la medición del consumo de

agua en un grifo de una unidad habitación, se logra reforzar y aplicar los conocimientos

adquiridos durante la carrera de ingeniería de sistemas como la programación, el desarrollo para

teléfonos móviles, la investigación, el análisis de requerimientos, el lenguaje unificado de

modelado (UML) y la construcción de bases de datos. De igual manera, se adquirieron nuevos

conocimientos respecto a las tecnologías inalámbricas, gracias a la interacción con la tecnología

ZigBee y los módulos XBee, que fueron parte especial en el desarrollo del proyecto.

Por otra parte, gracias al trabajo de investigación realizado nos pudimos dar cuenta de las

necesidades y problemáticas que pueden existir en un hogar, vivienda o unidad habitacional

respecto al consumo de agua, donde podemos decir que con el uso e implementación de las

tecnologías se puede contribuir en la conservación de este líquido vital.

Capítulo 4. Conclusiones

- La integración de diferentes herramientas tecnológicas como arduino, el sensor de

agua, el protocolo Zigbee y la aplicación móvil facilitan el proceso de monitorear el consumo

de agua, ayudando a reducir los gastos excesivos que se registran en una unidad habitacional.

- Con el desarrollo de este proyecto de investigación se logra introducir el protocolo

de comunicación Zigbee como una herramienta, ya que permite transferir información desde

los módulos XBee hasta la base de datos.

- Los módulos XBee serie 2, a pesar de tener un tamaño tan reducido, tiene una

gran funcionalidad, además de que permiten un ahorro de energía.

- El desarrollo de la base de datos permite registrar la información que genera el

sensor de flujo de agua para que luego sea visualizada en la aplicación móvil.

- La aplicación móvil permite ver en tiempo real el consumo de agua que se está

teniendo en el grifo, de igual manera saber el costo en pesos de ese consumo.

Referencias

Acevedo, C. M. D., & Iturriago, A. X. (2013). Automatización de un sistema de suministro de agua potable a través de la Tecnología Zigbee. Revista colombiana de tecnologías de avanzada(rcta), 2(20).

Aguado, J. M., Feijóo, C., & Martínez, I. J. (Eds.). (2013). La comunicación móvil: hacia un nuevo ecosistema digital. Barcelona, ESPAÑA: Editorial Gedisa. Retrieved from http://www.ebrary.com

Algarín, C. R. (2012). Diseño de un sistema Scada basado en Labview, implementando el protocolo de comunicación inalámbrica Zigbee. Prospectiva,10(1), 44-52.

Andrango Díaz, W. R., Ramírez, B., & Santiago, E. (2007). Diseño e implementación de una red inalámbrica para sufragio electrónico basada en el estándar ZIGBEE (IEEE802. 15.4).

Arroyo, N. (2011). Información en el móvil. Barcelona, ES: Editorial UOC. Retrieved from http://www.ebrary.com

Bustillos, J. R., Hernández, J., Silva, R. S., Barrón, V., Chávez, Ó. R., & López, S. A. (2016). El uso de la tecnología ZigBee y el suministro del agua potable. CULCyT, (54).

Cegarra, S. J. (2012). La tecnología. Madrid, ES: Ediciones Díaz de Santos. Retrieved from http://www.ebrary.com

Crespo, E. (3 de Febrero de 2017). Aperendiendo arduino . Obtenido de https://aprendiendoarduino.wordpress.com/tag/xbee/

Domínguez, M. F., Paredes, V. M., & Santacruz, V. L. P. (2014). Programación multimedia y dispositivos móviles. Madrid, ES: RA-MA Editorial. Retrieved from http://www.ebrary.com

Durán, P. D. C., & Iturriago, A. X. (2012). Automatización de un sistema de suministro de agua potable a través de la tecnología zigbee. Revista Colombiana de, 1(17), 2011.

Elmasri R., Navathe B. S. (2007). Fundamentos de sistemas de bases de datos.
España, Madrid: Pearson.

GUTIÉRREZ, L. G. (2012). Teoría de la medición de caudales y volúmenes de agua e instrumental necesario disponible en el mercado.

Herrador, R. E. (2009). Guía de usuario de Arduino. Universidad de Córdoba, 8.

Lozada, J. (2014). Investigación aplicada: definición, propiedad intelectual e industria.

Obtenido de http://www.uti.edu.ec/documents/investigacion/volumen3/06Lozada-2014.pdf (http://www.uti.edu.ec/documents/investigacion/volumen3/06Lozada-%20%20%20%20%20%20%20%20%20%20%20%20%20%20%20%20%20%20%202014.pdf)

Montalban, I. L., Perez, M. J., & Rivas, J. O. (2013). Bases de Datos. Madrid: Alfaomega.

Ojeda, E. (2009). Agua para el siglo XXI para América del Sur: de la visión a la acción. Informe Colombia.

Ordóñez, A. J. A., & Trejos, N. D. A. (2007). Los medidores de flujo (fluxómetros): mecánica de fluidos e hidráulica de tuberías. Buenos Aires, AR: El Cid Editor - Ingeniería. Retrieved from http://www.ebrary.com

Oppel, A. (2010). Fundamentos de bases de datos. México, D.F., MX: McGraw-Hill Interamericana. Retrieved from http://www.ebrary.com

Ortiz, F. (2005). Metodología de la investigación. México: LIMUSA

Osorio, J. A. C., Garzón, H. B. C., & Giraldo, E. E. (2008). Propuesta de aplicación" medición del consumo de agua domiciliaria" utilizando tecnología inalámbrica ZIGBEE. Scientia et Technica, 2(39), 43-47.

Pressman, R.S. (2005). Ingeniería del software, un enfoque práctico. México: McGraw-Hill

Reinoso Pérez, E. S. (2008). Diseño e implementación de un prototipo para una red de domótica y seguridad para un hogar utilizando el estándar IEEE 802.15. 4 ZIGBEE.

Robledo, S. C., & Fernández, D. R. (2011). Programación en Android. Madrid, ES: Ministerio de Educación de España. Retrieved from http://www.ebrary.com

Suárez Barón, J. C. (2014). Diseño y construcción de un sistema de monitoreo para invernaderos apoyado con tecnología Zigbee.

Vargas Cordero, Z R; (2009). La investigación aplicada: una forma de conocer las realidades con evidencia científica. Revista Educación, 33 () 155-165.

Anexos

Anexo 1: Fichas bibliográficas

FICHA 1

El uso de la tecnología ZigBee y el suministro del agua potable

Tema: Definición de ZigBee

Subtema: ZigBee

Ubicación: Carpeta Proyecto de Investigación

Referencia Bibliográfica (APA). Bustillos, J. R., Hernández, J., Silva, R. S., Barrón, V., Chávez, Ó. R., & López, S. A. (2016). El uso de la tecnología ZigBee y el suministro del agua potable. CULCyT, (54).

Resumen: Se define que es la tecnología ZigBee

Cita Textual 1. Es susceptible de ser utilizado para la automatización y medición del suministro de agua potable en redes domésticas.
P. 1
Cita Textual 2. ZigBee para la automatización y la medición del suministro de agua potable, así como la detección de fugas en la red en tiempo real. P. 1

Cita Textual 3. Según Ortúzar (2010) ZigBee es el nombre de la especificación de un conjunto de protocolos de alto nivel de comunicación inalámbrica para su utilización con radios digitales de bajo consumo, basada en el estándar IEEE 802.15.4 de redes inalámbricas de área personal (wireless personal area network, WPAN). Su objetivo son las aplicaciones para redes Wireless que requieran comunicaciones seguras y fiables con baja tasa de envío de datos y maximización de la vida útil de sus baterías.P2

Cita textual 4. El término de ZigBee debe su nombre a que el sistema de comunicación empleado es muy parecido al movimiento en zigzag que utilizan las abejas para comunicarse (Alfaro). Es decir, ZigBee trata de emular la coordinación de la comunicación y actividad de distintos individuos para poder actuar en conjunto para tareas más complejas. P2

Metodología.

FICHA 2

Diseño de un sistema Scada basado en labview, implementando el protocolo de

comunicación inalámbrica zigbee.

Comentarios. Zigbee es un protocolo de comunicación inalámbrico basado en el estándar IEEE 802.15.4

Tema: Tecnología ZigBee

Subtema: Módulos XBee

Ubicación: Carpeta Proyecto de Investigación

Referencia Bibliográfica (APA). Algarín, C. R. (2012). Diseño de un sistema Scada basado en Labview, implementando el protocolo de comunicación inalámbrica
Zigbee. Prospectiva,10(1), 44-52.

Resumen: Descripción de los módulos XBee

Cita Textual 1. Los dispositivos ZigBee escogidos para la comunicación inalámbrica son los módulos XBee ZB programables, con antena integrada (chip antenna), de la empresa DIGI, conocidos también como XBee Series 2.P. 48
Cita Textual 2. tienen un alcance máximo línea-vista de 120 metros para exteriores y de 40 metros en interiores. P. 48

Cita Textual 3. la tecnología ZigBee provista por los XBee Series 2, se puede constituir una red de datos confiable, con alta inmunidad al ruido, facilitando la comunicación entre los componentes del sistema y asegurando el correcto transporte de la información desde y hacia las unidades remotas. P. 51

Comentarios. Los módulos XBee son soluciones integradas

FICHA 3

Automatización de un sistema de suministro de agua potable a través de la tecnología zigbee.

FICHA 4

Ficha Bibliográfica Propuesta de aplicación “medición del consumo de agua domiciliaria”

utilizando tecnología inalámbrica Zigbee () {Bibliography}

Tema: Tecnología ZigBee

Subtema: ZigBee

Ubicación: Carpeta Proyecto de Investigación

Referencia Bibliográfica (APA). Acevedo, C. M. D., & Iturriago, A. X. (2013). Automatización de un sistema de suministro de agua potable a través de la Tecnología Zigbee. REVISTA COLOMBIANA DE TECNOLOGIAS DE AVANZADA (RCTA), 2(20).

Resumen: Se define que es la tecnología ZigBee

Cita Textual 1. El protocolo ZigBee es un estándar de las comunicaciones inalámbricas diseñado por la empresa ZigBee Alliance. Es un conjunto estandarizado de soluciones que pueden ser implementadas por cualquier fabricante
P. 2
Cita Textual 2. El ZigBee está basado en el estándar IEEE 802.15.4 de las redes inalámbricas WPAN, que tiene como objetivo ser implementada en aquellas aplicaciones donde se requieren comunicaciones seguras, confiables, de bajo consumo y coste.P. 2

Tema: Tecnología inalámbrica

Subtema: Tecnología Zigbee

Ubicación: Carpeta Proyecto Investigación

Referencia Bibliográfica (APA). Osorio, J. A. C., Garzón, H. B. C., & Giraldo, E. E. (2008). Propuesta de aplicación" medición del consumo de agua domiciliaria" utilizando tecnología inalámbrica ZIGBEE. Scientia et Technica, 2(39), 43-47.

Resumen: Se presentan fundamentos sobre la tecnología ZigBee y sus principales características.

Cita Textual 1. ZigBee es un protocolo que usa el 802.15.4 y es impulsado por ZigBee Alliance, un grupo de empresas, la mayoría fabricantes de semiconductores, que trabajan de manera conjunta en el desarrollo de este protocolo para aplicaciones comerciales e industriales de baja tasa de transferencia de datos y conectividad simple, teniendo en mente el uso de baterías en los dispositivos. p. 1
Cita Textual 2. El ancho de banda definido por el estándar 802.15.4 es de 5 MHz en la banda de 2,4 GHz 1 (aunque en la práctica sólo se usan 2 MHz) y la tasa de transferencia de datos máxima es de 250 Kbps. Además, especifica el uso de "Direct Sequence Spread Spectrum" (DSSS) y el uso de modulación O-QPSK (Offset Quadrature Phase Shift Keying) con forma de pulso de media onda sinusoidal para la modulación de la frecuencia portadora. p.1

Cita Textual 3. Está basada en el estándar IEEE 802.15.4, acceso físico y capa de acceso a los medios de comunicación (Physical Layer (PHY) y Media Access Layer (MAC)) de redes inalámbricas de área personal (wireless personal area network, WPAN)2. Su objetivo son las aplicaciones que requieren comunicaciones seguras con baja tasa de envío de datos y maximización de la vida útil de sus baterías. p. 2

Cita Textual 4. ZigBee además de tener un radio transmisor/receptor, tiene un microcontrolador que puede ser programado según las necesidades, evitando la construcción de interfaces con otros dispositivos, y la utilización de más hardware. Asimismo, incorpora la creación de redes en malla. p. 2

Cita Textual 5. La topología más interesante (y una de las causas por las que parece que puede triunfar ZigBee) es la topología en malla; ya que esta permite que si, en un momento dado, un nodo del camino falla y se cae, pueda seguir la comunicación entre todos los demás nodos debido a que se rehacen todos los caminos. p. 3

Cita Textual 6. Una red ZigBee puede constituirse hasta por 255 nodos, los cuales tienen la mayor parte del tiempo el transceiver ZigBee en reposo, con el objeto de disminuir el consumo, cosa que no ocurre con otras tecnologías inalámbricas. Un sensor equipado con un transceiver ZigBee puede alimentarse con dos pilas AA durante al menos 6 meses y hasta 2 años. p. 3

Metodología.

Tema: Propuesta aplicación ZigBee

Subtema: Componentes

Ubicación: Carpeta Proyecto Investigación

Referencia Bibliográfica (APA). Osorio, J. A. C., Garzón, H. B. C., & Giraldo, E. E. (2008). Propuesta de aplicación" medición del consumo de agua domiciliaria" utilizando tecnología inalámbrica ZIGBEE. Scientia et Technica, 2(39), 43-47.

Resumen: Se presentan una propuesta de aplicación con tecnología ZigBee, con el fin de automatizar un sistema de medición del consumo de agua a nivel residencial.

Cita Textual 1. Actualmente la medición del caudal de agua para el servicio domiciliario y su posterior cobro, se realiza por medio de un contador, que indica el valor por medio de un mecanismo similar al de un odómetro. La lectura de este valor es realizada por un funcionario quien debe ir hasta la residencia y anotar los valores correspondientes del consumo. p. 3
Cita Textual 2. La propuesta incluye la medición del caudal de agua en los contadores, empleando un sensor de efecto hall que ofrece alto grado de exactitud; así como brinda la posibilidad de generar una señal en caso de ausencia de agua. p. 4

Cita Textual 3. se emplea una red GPRS para enviar toda la información a un centro de control. La unión del sensor con la red GPRS se realiza usando la tecnología ZigBee. p. 4

Cita Textual 4. la red GPRS será la encargada de recibir por medio de un modem los datos de los sensores que están conectados, y mandarlos por la red a un centro de administración y control donde exista señal de celular. p.4

Cita Textual 5. Sensor de efecto HALL: El efecto Hall consiste en la aparición de un campo eléctrico en un conductor cuando es atravesado por un campo magnético. A este campo eléctrico se le llama campo Hall. El efecto Hall es llamado así en honor a su descubridor Edwin Duntey Hall. p. 4

Cita Textual 6. Dentro de las aplicaciones relacionadas con el efecto hall vale anotar: Determinación de la variación de los campos magnéticos; implementación de medidores de campo magnético (Teslámetro); detección de cambios en la intensidad de corrientes eléctricas (sensores de corriente de Efecto Hall); también permiten la elaboración de sensores o detectores de posición sin contacto, utilizados

FICHA 5

Automatización de un sistema de suministro de agua potable a través de la tecnología

ZIGBEE

particularmente en el automóvil, para detectar la posición de un árbol giratorio (caja de cambios); se encuentran también sensores de efecto Hall bajo las teclas de los

teclados de ciertos instrumentos musicales modernos (órganos, órganos digitales, sintetizadores) evitando así el desgaste que sufren los contactos eléctricos tradicionales; se hallan sensores de efecto Hall en el codificador de un motor de CD; los motores de Efecto Hall (HET) son aceleradores de plasma de gran eficacia.

Tema: Automatización de un sistema de suministro de agua potable a través de la tecnología ZIGBEE

Subtema: Tecnologías

Ubicación: Carpeta Proyecto de Investigación

Referencia Bibliográfica (APA). Durán, P. D. C., & Iturriago, A. X. (2012). AUTOMATIZACIÓN DE UN SISTEMA DE SUMINISTRO DE AGUA POTABLE A TRAVÉS DE LA TECNOLOGÍA ZIGBEE. Revista Colombiana de, 1(17), 2011.

Resumen: Se describe las tecnologías utilizadas para el desarrollo del proyecto y sus beneficios

Cita Textual 1. Las tecnologías inalámbricas han adoptado, en el transcurso del tiempo, una manera más sencilla y cómoda de utilizar toda clase de dispositivos con el fin de mejorar el uso y las comunicaciones en general. P. 1
Cita Textual 2. ZigBee comunica una serie de dispositivos haciendo que trabajen más eficientemente entre sí. P.1

Cita Textual 3. El software a utilizar para la instrumentación o interfaz virtual es LabView ya que, debido a su interfaz de comunicación amigable para el usuario, nos permite de una manera gráfica configurar todas y cada uno de los dispositivos de nuestro sistema a controlar. P.2

Cita Textual 4. los módulos inalámbricos utilizados para realizar la comunicación bidireccional para la trasmisión y recepción de los datos para ser adquiridos a través del PC (Computador personal), fue mediante dispositivos XBEE de la Serie 1 modelo IC: 4214A-XBEE con capacidad de hasta de 8 entradas y salidas digitales; el cual

Anexo 2: Criterios de evaluación del prototipo cuenta con las ventajas de tener gran flexibilidad en la configuración del sistema. P.2

Cita Textual 5. Para el control del proceso del sistema de suministro de agua, el llenado del tanque se emplearon dispositivos de control y automatización, con el objetivo de mantener en funcionamiento el sistema sin necesidad de la intervención de un operario para el modo automático. P.3

Cita Textual 6. El uso de varias herramientas como los microcontroladores, módulos inalámbricos y la instrumentación virtual o interfaz gráfica son de gran importancia debido a que la aplicación de estos sistemas abre la posibilidad de hacerlos más flexibles y robustos. P. 5

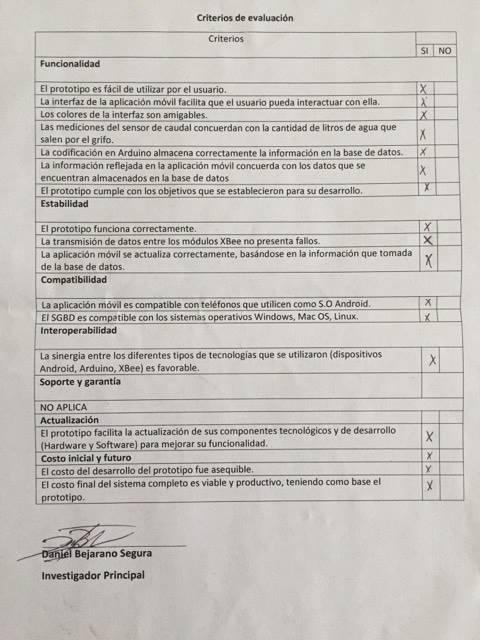
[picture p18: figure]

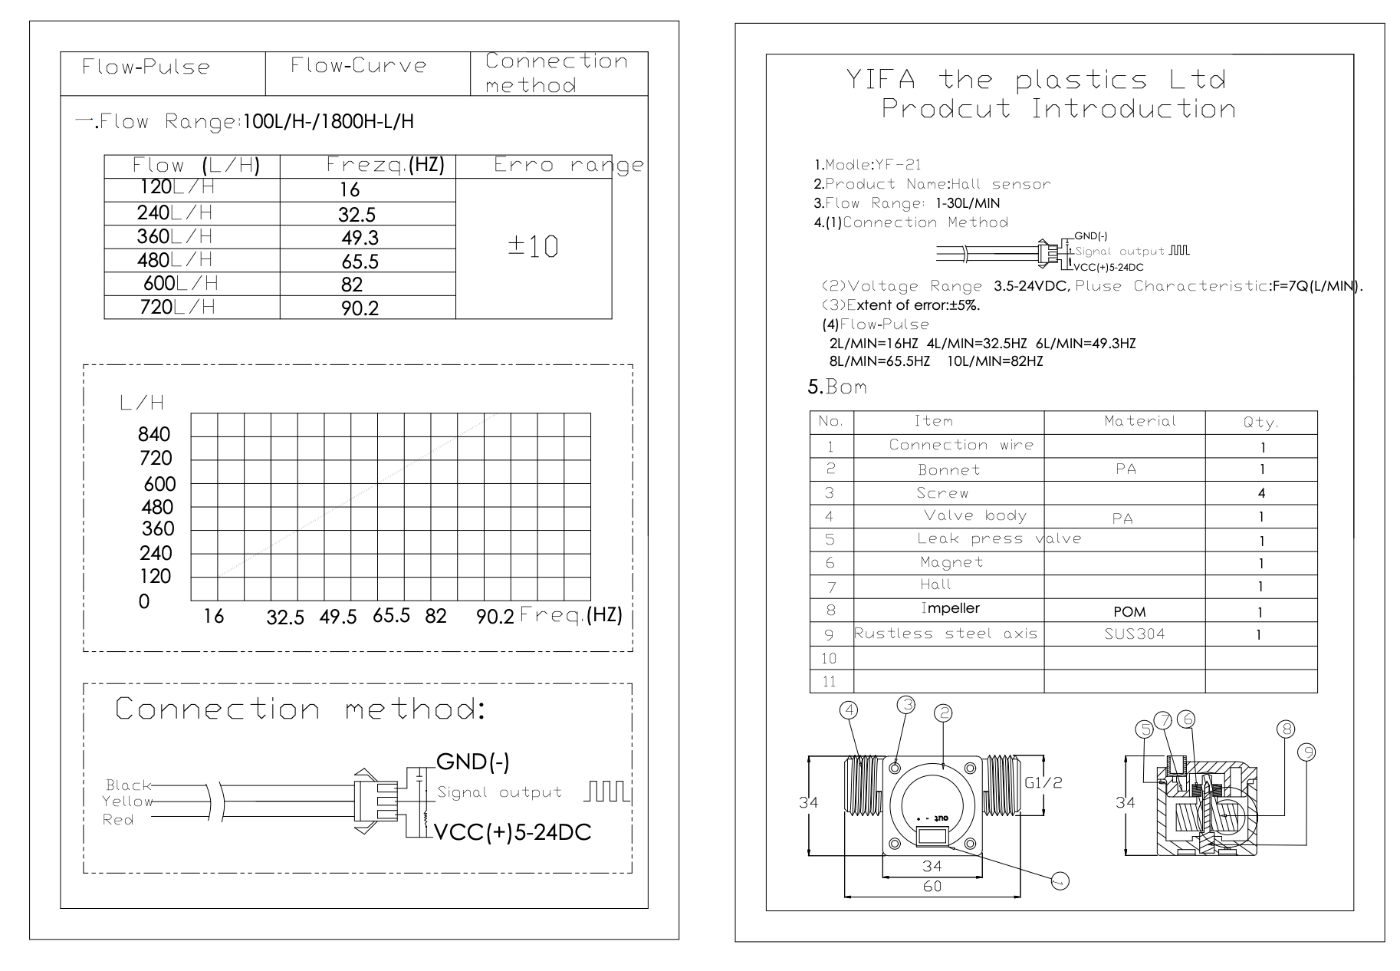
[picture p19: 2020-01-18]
Hardware/DataSheets/YF-S201 DATASHEET.png

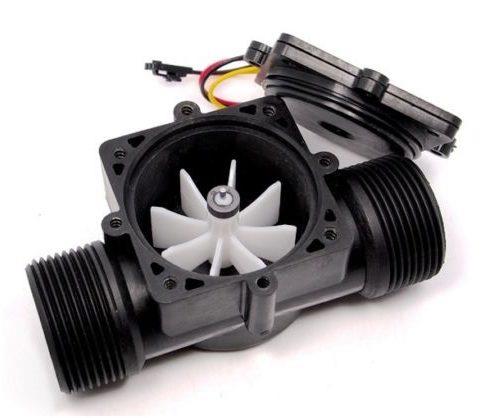
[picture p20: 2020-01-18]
Hardware/DataSheets/YF-S201.jpg

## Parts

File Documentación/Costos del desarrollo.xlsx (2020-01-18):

ITEM | ACTIVIDAD | TIEMPO DE EJECUCIÓN ( SEMANAS ) | EJECUTADO | COSTO
1 | DISEÑO Y DESARROLLO DEL SISTEMA DE SENSORES | 4 | 50% | $600000
2 | DISEÑO DE LA BASE DE DATOS | 1 | 25% | $200000
3 | DISEÑO Y DESARROLLO DEL SERVICIO WEB | 6 | 0% | $800000
4 | DISEÑO Y DESARROLLO DE LA APLICACIÓN WEB | 3 | 0% | $400000
5 | DISEÑO Y DESARROLLO DE LA APLICACIÓN MOVIL ANDROID | 4 | 0% | $200000
6 | PRUEBAS Y CORRECIÓN DE ERRORES | 3 | 0% | $0
7 | DOCUMENTACIÓN TÉCNICA DEL SISTEMA | 2 | 80% | $0
8 | DESPLIEGUE DEL SISTEMA EN LA NUBE | 1 | 0% | $0
9 | SOPORTE TÉCNICO DEL SISTEMA HASTA LA SUSTENTACIÓN DEL PROYECTO |  | 0% | $0
 | TIEMPO DE DESARROLLO REQUERIDO | 24
 | COSTO TOTAL DEL DESARROLLO |  |  | $2200000

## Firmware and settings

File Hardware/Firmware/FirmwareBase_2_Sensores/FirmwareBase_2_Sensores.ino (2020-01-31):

#include <ESP8266WiFi.h>
#include <WiFiClient.h>

#ifndef STASSID
#define STASSID "FAMILIA_GALLEGO"
#define STAPSK  "10091467hernando"
#endif

const char* ssid     = STASSID;
const char* password = STAPSK;

int Pin = 2;
int Pin2 = 14;

int flowPin1 = 5;
int flowPin2 = 4;

unsigned long flow1count = 0;
unsigned long flow2count = 0;

void setup()
{
    pinMode(Pin, OUTPUT);
    pinMode(Pin2, OUTPUT);
    digitalWrite(Pin, LOW);
    digitalWrite(Pin2, HIGH);
    Serial.begin(9600);
    Serial.print("Conectando a : ");
    Serial.println(ssid);

    WiFi.mode(WIFI_STA);
    WiFi.begin(ssid, password);

    while (WiFi.status() != WL_CONNECTED) {
      digitalWrite(Pin, HIGH);
      digitalWrite(Pin2, LOW);
      delay(150);
      digitalWrite(Pin, LOW);
      digitalWrite(Pin2, HIGH);
      delay(150);
      Serial.print(".");
    }
    
    Serial.println("");
    digitalWrite(Pin, HIGH);
    digitalWrite(Pin2, LOW);
    Serial.println("WiFi connectado");
    Serial.println("IP: ");
    Serial.println(WiFi.localIP());
    
    pinMode(flowPin1, INPUT_PULLUP);
    attachInterrupt(flowPin1, flow1, CHANGE);
    pinMode(flowPin2, INPUT_PULLUP);
    attachInterrupt(flowPin2, flow2, CHANGE);
}

void loop()
{
  Serial.print("Sensor 1: ");
  Serial.print(flow1count/450.0);
  Serial.print("Sensor 2: ");
  Serial.println(flow2count/450.0);
  //Serial.print("\tFlow 1 in pulses: ");
  //Serial.print(flow1count);
  //Serial.print("\tFlow 2 in pulse: ");
  //Serial.println(flow2count);
  delay(5000);
}

void flow1()
{
  flow1count +=1;
}

void flow2()
{
  flow2count +=1;
}

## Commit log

2019-10-17 Primer commit
    Integración de la plantilla adminLite v3
2019-10-17 Depuracion de plantilla - Panel de control
2019-10-17 Se ajusta menú de navegación
2019-10-17 Se agregan hojas de datos del hardware
2019-10-30 Scripts iniciales para despliegue de base de datos
2020-01-18 Se agrega documentación técnica del sistema
    [BOARD V1.fzz, Costos del desarrollo.xlsx]
2020-01-18 Se corrige el nombre del documento
2020-01-22 Se agrega templete del panel de administración.
    [Costos del desarrollo.xlsx]
2020-01-22 Se actualiza script de despliegue de BD
2020-01-31 Se agrega firmware base para realizar lecturas desde múltiples sensores
